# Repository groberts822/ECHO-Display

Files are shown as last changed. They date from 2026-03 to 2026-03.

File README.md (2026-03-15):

# ECHO-Display
ECHO, or Embedded Controller &amp; Hidden Operations. Music display by day, game console by night.
To begin, I started working on my schematic. It was quite simple, I chose to 2 1x7 headers instead of going through the pain to spend forever searching through the internet for the right symbol and footprint of the esp32. 
I prefer to use net labels, especially with schematics that are this simple, so here's my schematic below:



In addition, my PCB was quite simple, however it took some measurements, where I used the provided STEP files and just measured the necessary sizes in fusion. 
The 1x7 headers for the ESP32 ARE spaced out correctly (Again, made sure by measuring the part in fusion), and I made sure the display had enough space so it wouldnt cover the switches. I also chose to do the esp32 on the back side, the display ontop, and the switches lined up below the display. I also added mounting holes and added a custom logo to my pcb just for fun (and mounting holes for mounting to case). Below is the PCB: 



In addition, I used the provided STEP files to make the 3D viewer. Just a note, the DIsplay does not have headers in this 3D viewer, because they are specially spaced pins (3mm apart not 2.54mm), so I will have 
to use the header pins which come with the display itself. I also made sure to adjust the footprint so that it was actually 3mm apart and would work. Below is the 3D model: 



Backside: 



Next I saved the STEP for the board with the parts, and moved on over to fusion. I utilized the mounting holes and provided holes on each side of it, so I can use heat-set inserts on the bottom half, and then use screws to secure the top half and pcb into place. I chose to go with somewhat of a unique spotify display design, as I made it so the display was sideways and ontop, then the 3 switches below it, and it was like a stand proped up almost in the shape of an iphone holder. Below are some images of the 3D model: 









I would like to note, there are holes for heat-press inserts, which I have myself, alongside the proper screws, so unless it comes in the kit for this starter project, I dont need them hence why they aren't separately mentioned in the BOM. 

After basically finishing the whole 3D modelling and such, I worked on the firmware, where although I cannot put here, I provided a snippet of the code below, with the full thing being in the github repo:



BOM is below:

| Qty | Part | Link | Notes |
|-----|---|---|---|
| 1 | ESP32 LOLIN C3 Mini | [AliExpress](https://www.aliexpress.us/item/3256804553736450.html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) | |
| 1 | 1.8" TFT Display ST7735 | [AliExpress](https://www.aliexpress.us/item/3256809750593574.html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"order"%3A"199"%2C"eval"%3A"1"%2C"fromPage"%3A"search"%7D&pdp_npi=6%40dis%21USD%218.14%210.99%21%21%2155.72%216.76%21%40210311cc17736153139033443ee5db%2112000050625051194%21sea%21US%217425461850%21ABX%211%210%21n_tag%3A-29910%3Bd%3A6670291b%3Bm03_new_user%3A-29895%3BpisId%3A5000000197847475&curPageLogUid=sl2faarfQKwY&utparam-url=scene%3Asearch%7Cquery_from%3A%7Cx_object_id%3A1005009936908326%7C_p_origin_prod%3A&_gl=1*4nhmo6*_gcl_au*OTExMzQxMzAyLjE3NzM2MTUyNjg.*_ga*MTY2NjQwMzk4OC4xNzczNjE1MjY4*_ga_VED1YSGNC7*czE3NzM2MTUyNjgkbzEkZzEkdDE3NzM2MTUzMTIkajE2JGwwJGgw) | |
| 1 | Custom PCB | [JLCPCB](https://jlcpcb.com) | Already ordered |
| 3 | Cherry MX Switches | [NovelKeys](https://novelkeys.com/products/cherry-mx2a-switches) | Leftover from Hackpad |
| 3 | Keycaps (1u) | [NovelKeys](https://novelkeys.com) | Leftover from Hackpad |
| 4 | M3 Heatset Inserts | [Amazon](https://www.amazon.com/initeq-M3-0-5-Threaded-Inserts-Printing/dp/B077CJV3Z9) | Leftover from Hackpad |
| 4 | M3 Screws | [Amazon](https://www.amazon.com/s?k=m3+screws) | Leftover from Hackpad |

All files have been uploaded to the github repo, and just to be sure I had also provided the gerber files so its easier to just take them straight off of there when I order the pcb. 
Lastly, ECHO, or Embedded Controller & Hidden Operations (yes I know the name is weird, it'll make sense), is a desk Spotify display built using an ESP32 C3 Mini, alongside a 1.8" TFT screen, 3 mechanical switches for playback control, and a hidden Space Invaders game unlocked by holding all 3 keys (hence the "& Hidden Operations").
The display shows your current track with mood-based colors, scrolling text, animated bars, and a progress bar. The PCB was (although as expected) built in KiCad while the case was designed around the full PCB in Fusion360. 
The project includes a Case folder with CAD files, a PCB folder with all KiCad and manufacturing files, and Firmware folder with the Arduino firmware. 
I would also like to point out. The PCB was not needed for this project, however, I am still working on my PCB designing skills so I could use the challenge. Also, the firmware provided is NOT the final version, as I can only really finish it once I have the ESP32 and know its IP. 

Thanks for checking out ECHO. And don't forget to hold all 3 keys. 

Adobe Express - file

Github Repo Link: 
https://github.com/groberts822/ECHO-Display

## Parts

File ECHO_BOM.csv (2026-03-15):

Qty | Part | Link | Notes
----- | ------ | ------ | -------
1 | ESP32 LOLIN C3 Mini | [AliExpress](https://www.aliexpress.us/item/3256804553736450.html
1 | 1.8" TFT Display ST7735 | [AliExpress](https://www.aliexpress.us/item/3256809750593574.html?pdp_ext_f=%7B"order"%3A"199"%2C"eval"%3A"1"%2C"fromPage"%3A"search"%7D&pdp_npi=6%40dis%21USD%218.14%210.99%21%21%2155.72%216.76%21%40210311cc17736153139033443ee5db%2112000050625051194%21sea%21US%217425461850%21ABX%211%210%21n_tag%3A-29910%3Bd%3A6670291b%3Bm03_new_user%3A-29895%3BpisId%3A5000000197847475&curPageLogUid=sl2faarfQKwY&utparam-url=scene%3Asearch%7Cquery_from%3A%7Cx_object_id%3A1005009936908326%7C_p_origin_prod%3A&_gl=1*4nhmo6*_gcl_au*OTExMzQxMzAyLjE3NzM2MTUyNjg.*_ga*MTY2NjQwMzk4OC4xNzczNjE1MjY4*_ga_VED1YSGNC7*czE3NzM2MTUyNjgkbzEkZzEkdDE3NzM2MTUzMTIkajE2JGwwJGgw)
1 | Custom PCB | [JLCPCB](https://jlcpcb.com) | Already ordered to save time, dont need reimbursement or grant for this
3 | Cherry MX Switches | [NovelKeys](https://novelkeys.com/products/cherry-mx2a-switches) | Leftover from Hackpad, dont need grant for this
3 | Keycaps (1u) | [NovelKeys](https://novelkeys.com) | Leftover from Hackpad, dont need grant for this
4 | M3 Heatset Inserts | [Amazon](https://www.amazon.com/initeq-M3-0-5-Threaded-Inserts-Printing/dp/B077CJV3Z9) | Leftover from Hackpad, dont need grant for this
4 | M3 Screws | [Amazon](https://www.amazon.com/s?k=m3+screws) | Leftover from Hackpad, dont need grant for this

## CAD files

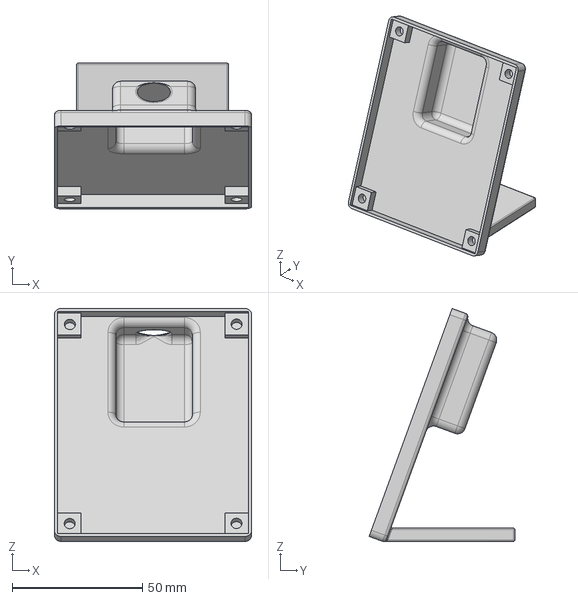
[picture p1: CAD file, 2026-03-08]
ECHO_CAD/ECHO Case (Bottom).step
75.7 x 55.9 x 89.4 mm

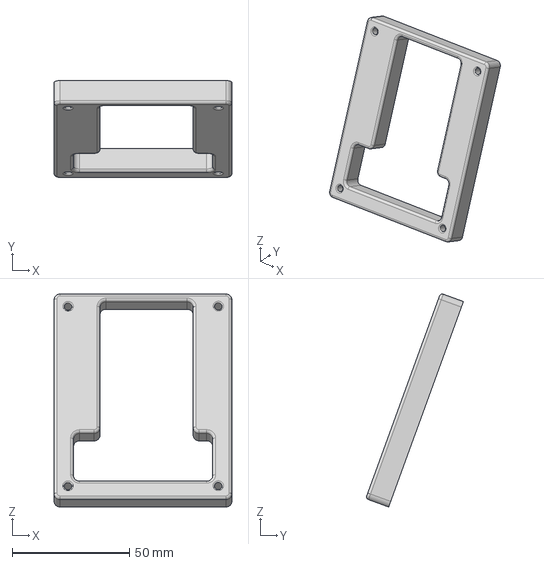
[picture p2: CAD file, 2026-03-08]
ECHO_CAD/ECHO Case (Top).step
75.7 x 41.3 x 90.7 mm

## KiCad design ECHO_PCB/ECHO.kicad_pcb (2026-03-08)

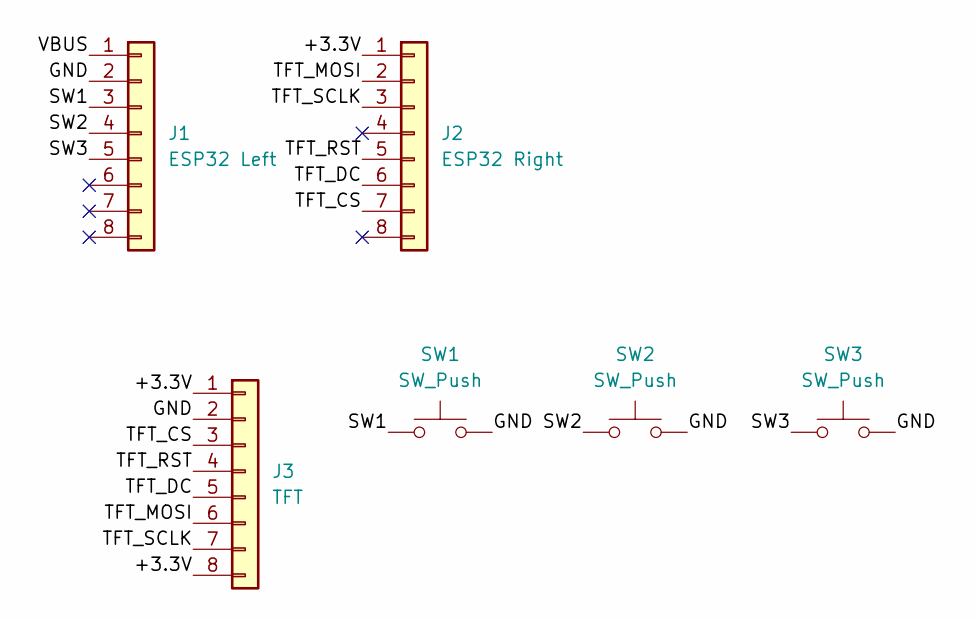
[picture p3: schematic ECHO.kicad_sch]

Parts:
J1: ESP32 Left; PinSocket_1x08_P2.54mm_Vertical
J2: ESP32 Right; PinSocket_1x08_P2.54mm_Vertical
J3: TFT; PinSocket_1x08_P2.54mm_Vertical
SW1, SW2, SW3: SW_Push; SW_Cherry_MX_1.00u_PCB

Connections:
/+3.3V: J2.1, J3.1, J3.8
/GND: J1.2, J3.2, SW1.2, SW2.2, SW3.2
/SW1: J1.3, SW1.1
/SW2: J1.4, SW2.1
/SW3: J1.5, SW3.1
/TFT_CS: J2.7, J3.3
/TFT_DC: J2.6, J3.5
/TFT_MOSI: J2.2, J3.6
/TFT_RST: J2.5, J3.4
/TFT_SCLK: J2.3, J3.7
/VBUS: J1.1

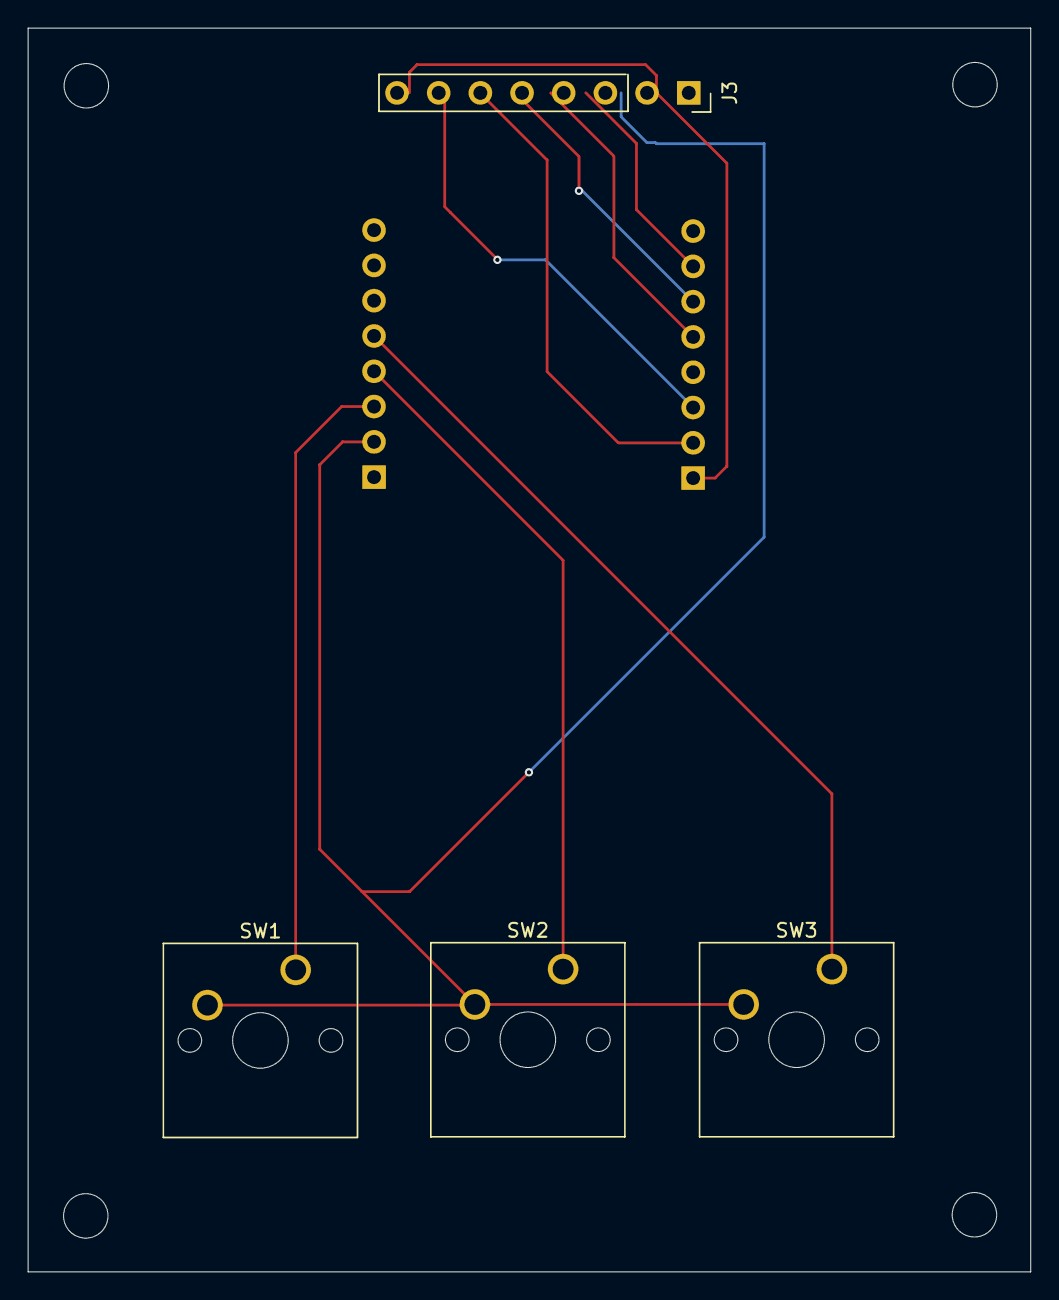
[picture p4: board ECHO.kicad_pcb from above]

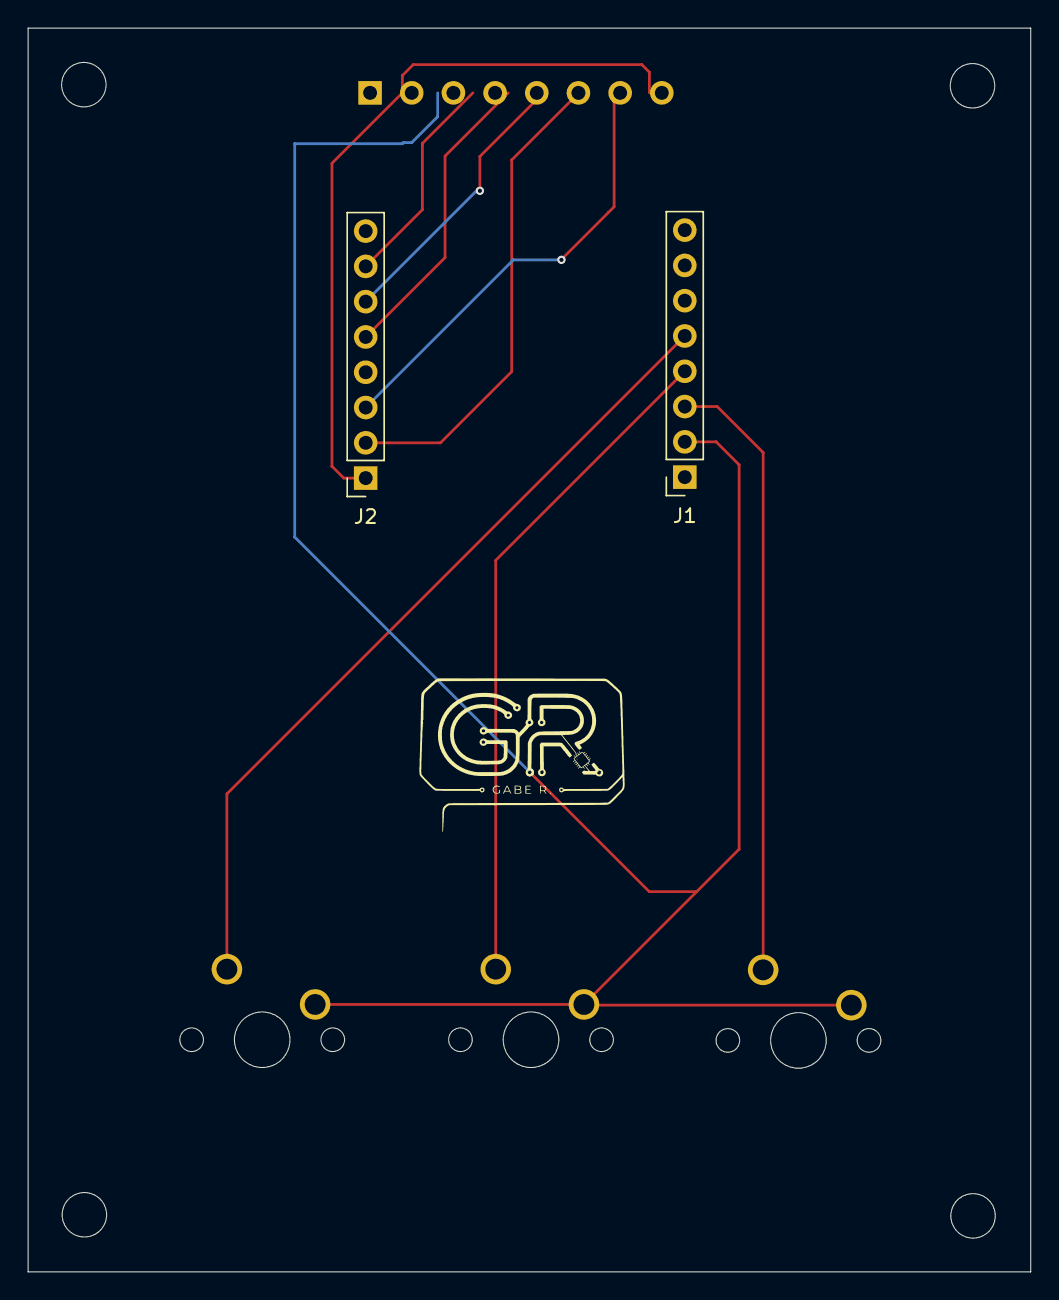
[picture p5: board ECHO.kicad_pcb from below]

Board: 2 copper layers, 72.2 x 89.5 mm, 6 parts (2 on the bottom side), 10 nets.

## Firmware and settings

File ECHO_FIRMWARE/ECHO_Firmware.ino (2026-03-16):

#include <Arduino.h>
#include <ArduinoJson.h>
#include <Adafruit_GFX.h>
#include <Adafruit_ST7735.h>
#include <WiFi.h>
#include <SpotifyEsp32.h>
#include <SPI.h>

char* SSID     = "My WiFi SSID";
char* PASS     = "My WiFi Password";
const char* CLID  = "My Spotify Client ID";
const char* CLSEC = "My Spotify Client Secret";

#define TFT_CS    3
#define TFT_RST   1
#define TFT_DC    2
#define TFT_SCLK  4
#define TFT_MOSI  5

#define BTN_L  6
#define BTN_M  7
#define BTN_R  8

Adafruit_ST7735 tft = Adafruit_ST7735(TFT_CS, TFT_DC, TFT_MOSI, TFT_SCLK, TFT_RST);
Spotify sp(CLID, CLSEC);

#define SW 160
#define SH 128

// rough mood colors - not using audio features api, just proxying off name length for now
// TODO: hook into actual valence/energy endpoint when i have time
#define C_HYPE   tft.color565(180, 0, 0)
#define C_HAPPY  tft.color565(180, 120, 0)
#define C_CHILL  tft.color565(0, 80, 160)
#define C_SAD    tft.color565(40, 0, 80)
#define C_DEF    tft.color565(0, 0, 0)

String trkName  = "";
String trkArtist = "";
bool   playing  = false;
int    scrollOff = 0;
unsigned long tScroll = 0;
unsigned long tPoll   = 0;
uint16_t moodCol = C_DEF;

int bH[3] = {10, 20, 15};
int bT[3] = {10, 20, 15};
unsigned long tBar = 0;

// progress is faked rn - SpotifyEsp32 doesnt expose it cleanly
// leaving at 0.5 until i find a workaround
float prog = 0.5;

bool b1Lst = HIGH, b2Lst = HIGH, b3Lst = HIGH;
unsigned long bHoldT = 0;
bool held = false;

bool gMode = false;

#define N_INV  12
#define N_BLTS  4

struct Inv { int x, y; bool alive; };
struct Blt { int x, y; bool on; };

Inv invs[N_INV];
Blt pBullets[N_BLTS];
Blt iBullet;

int pX    = SW / 2;
int lives = 3;
int score = 0;
int iDir  = 1;
unsigned long tTick = 0;
bool gOver = false;
bool gWon  = false;

void drawSp();
void drawBars();
uint16_t moodColor(String t);
void checkHold();
void runGame();
void initGame();
void drawGame();
void moveInvs();
void movePBullets();
void moveIBullet();
void checkHits();
void drawShip();
void clearShip(int x);
void scrGameOver();
void scrWin();

void setup() {
  Serial.begin(115200);

  pinMode(BTN_L, INPUT_PULLUP);
  pinMode(BTN_M, INPUT_PULLUP);
  pinMode(BTN_R, INPUT_PULLUP);

  tft.initR(INITR_BLACKTAB);
  tft.setRotation(1);
  tft.fillScreen(ST77XX_BLACK);

  tft.setTextSize(3);
  tft.setTextColor(ST77XX_WHITE);
  tft.setCursor(40, 50);
  tft.print("ECHO");
  delay(1000);
  tft.fillScreen(ST77XX_BLACK);

  tft.setTextSize(1);
  tft.setTextColor(ST77XX_WHITE);
  tft.setCursor(0, 0);
  tft.print("Connecting...");
  WiFi.begin(SSID, PASS);
  int dots = 0;
  while (WiFi.status() != WL_CONNECTED) {
    delay(500);
    tft.print(".");
    if (++dots > 20) {
      tft.fillScreen(ST77XX_BLACK);
      tft.setCursor(0, 0);
      dots = 0;
    }
  }

  tft.fillScreen(ST77XX_BLACK);
  tft.setCursor(0, 0);
  tft.print("WiFi up");
  tft.setCursor(0, 12);
  tft.print(WiFi.localIP().toString().c_str());
  delay(2000);

  tft.fillScreen(ST77XX_BLACK);
  tft.setCursor(0, 0);
  tft.print("Spotify auth...");
  tft.setCursor(0, 12);
  tft.print("open IP in browser");
  sp.begin();
  while (!sp.is_auth()) sp.handle_client();

  tft.fillScreen(ST77XX_BLACK);
  tft.setCursor(0, 0);
  tft.print("good to go");
  delay(800);
  tft.fillScreen(ST77XX_BLACK);
}

void loop() {
  checkHold();

  if (gMode) {
    runGame();
    return;
  }

  if (millis() - tPoll > 2000) {
    tPoll = millis();
    drawSp();
  }

  // scroll if name too long
  if (millis() - tScroll > 200 && trkName.length() > 18) {
    tScroll = millis();
    if (++scrollOff > (int)trkName.length()) scrollOff = 0;
    tft.fillRect(0, 40, SW, 16, moodCol);
    tft.setTextColor(ST77XX_WHITE);
    tft.setTextSize(2);
    tft.setCursor(0, 40);
    String s = trkName.substring(scrollOff) + "   " + trkName.substring(0, scrollOff);
    tft.print(s.substring(0, 13));
  }

  if (millis() - tBar > 150 && playing) {
    tBar = millis();
    drawBars();
  }
}

void drawSp() {
  String trk = sp.current_track_name();
  String art  = sp.current_artist_names();
  bool   isP  = sp.is_playing();

  if (trk == "Something went wrong" || trk == "null" || trk.isEmpty()) return;

  bool changed = (trk != trkName || art != trkArtist || isP != playing);
  if (!changed) {
    // still update progress bar even if nothing changed
    int bw = (int)(prog * SW);
    tft.fillRect(0, SH - 6, SW, 6, tft.color565(50, 50, 50));
    tft.fillRect(0, SH - 6, bw, 6, ST77XX_GREEN);
    return;
  }

  trkName   = trk;
  trkArtist = art;
  playing   = isP;
  scrollOff = 0;

  moodCol = moodColor(trk);
  tft.fillScreen(moodCol);

  tft.setTextSize(1);
  tft.setTextColor(ST77XX_WHITE);
  tft.setCursor(0, 0);
  tft.print(isP ? ">> NOW PLAYING" : "|| PAUSED");

  tft.setCursor(0, 20);
  String a = art.length() > 26 ? art.substring(0, 26) : art;
  tft.print(a.c_str());

  tft.setTextSize(2);
  tft.setCursor(0, 40);
  tft.print(trk.substring(0, 13).c_str());

  drawBars();

  int bw = (int)(prog * SW);
  tft.fillRect(0, SH - 6, SW, 6, tft.color565(50, 50, 50));
  tft.fillRect(0, SH - 6, bw, 6, ST77XX_GREEN);
}

void drawBars() {
  int bw = 8, gap = 4;
  int sx = SW - (3 * bw + 2 * gap) - 4;
  int by = SH - 10;
  int mh = 30;

  for (int i = 0; i < 3; i++) {
    if (random(10) > 6) bT[i] = random(6, mh);
    if (bH[i] < bT[i]) bH[i]++;
    else if (bH[i] > bT[i]) bH[i]--;
    int x = sx + i * (bw + gap);
    tft.fillRect(x, by - mh, bw, mh, moodCol);
    tft.fillRect(x, by - bH[i], bw, bH[i], ST77XX_GREEN);
  }
}

uint16_t moodColor(String t) {
  int l = t.length();
  if (l < 5)  return C_SAD;
  if (l < 10) return C_CHILL;
  if (l < 15) return C_HAPPY;
  return C_HYPE;
}

void checkHold() {
  bool b1 = digitalRead(BTN_L) == LOW;
  bool b2 = digitalRead(BTN_M) == LOW;
  bool b3 = digitalRead(BTN_R) == LOW;

  if (b1 && b2 && b3) {
    if (!held) { held = true; bHoldT = millis(); }
    else if (millis() - bHoldT > 2000) {
      gMode = !gMode;
      held  = false;
      if (gMode) initGame();
      else { tft.fillScreen(ST77XX_BLACK); trkName = ""; }
      delay(500);
    }
  } else {
    held = false;
  }
}

void initGame() {
  tft.fillScreen(ST77XX_BLACK);
  pX = SW / 2; lives = 3; score = 0;
  gOver = false; gWon = false; iDir = 1;

  for (int i = 0; i < N_BLTS; i++) pBullets[i].on = false;
  iBullet.on = false;

  int idx = 0;
  for (int r = 0; r < 3; r++)
    for (int c = 0; c < 4; c++)
      invs[idx++] = { 10 + c * 35, 10 + r * 18, true };

  drawGame();
}

void runGame() {
  if (gOver) { scrGameOver(); return; }
  if (gWon)  { scrWin();      return; }

  bool b1 = digitalRead(BTN_L) == LOW;
  bool b2 = digitalRead(BTN_M) == LOW;
  bool b3 = digitalRead(BTN_R) == LOW;

  if (b1 && pX > 4)         { clearShip(pX); pX -= 3; }
  if (b3 && pX < SW - 12)   { clearShip(pX); pX += 3; }

  static unsigned long tShot = 0;
  if (b2 && millis() - tShot > 300) {
    tShot = millis();
    for (int i = 0; i < N_BLTS; i++) {
      if (!pBullets[i].on) {
        pBullets[i] = { pX + 4, SH - 20, true };
        break;
      }
    }
  }

  if (millis() - tTick > 60) {
    tTick = millis();
    moveInvs(); movePBullets(); moveIBullet(); checkHits(); drawGame();
  }
}

void drawGame() {
  tft.fillScreen(ST77XX_BLACK);
  tft.setTextSize(1);
  tft.setTextColor(ST77XX_WHITE);
  tft.setCursor(0, 0);  tft.print("SC:"); tft.print(score);
  tft.setCursor(100, 0); tft.print("HP:"); tft.print(lives);

  for (int i = 0; i < N_INV; i++) {
    if (!invs[i].alive) continue;
    tft.fillRect(invs[i].x, invs[i].y, 10, 8, ST77XX_GREEN);
    tft.drawPixel(invs[i].x + 2, invs[i].y - 2, ST77XX_GREEN);
    tft.drawPixel(invs[i].x + 7, invs[i].y - 2, ST77XX_GREEN);
  }

  for (int i = 0; i < N_BLTS; i++)
    if (pBullets[i].on)
      tft.fillRect(pBullets[i].x, pBullets[i].y, 2, 6, ST77XX_YELLOW);

  if (iBullet.on)
    tft.fillRect(iBullet.x, iBullet.y, 2, 6, ST77XX_RED);

  drawShip();
}

void drawShip() {
  tft.fillTriangle(pX, SH-10, pX+8, SH-10, pX+4, SH-18, ST77XX_CYAN);
}

void clearShip(int x) {
  tft.fillRect(x, SH - 20, 10, 12, ST77XX_BLACK);
}

void moveInvs() {
  static int mv = 0;
  if (++mv < 3) return;
  mv = 0;

  bool edge = false;
  for (int i = 0; i < N_INV; i++) {
    if (!invs[i].alive) continue;
    invs[i].x += iDir * 2;
    if (invs[i].x > SW - 12 || invs[i].x < 0) edge = true;
  }
  if (edge) {
    iDir *= -1;
    for (int i = 0; i < N_INV; i++)
      if (invs[i].alive) invs[i].y += 6;
  }

  if (!iBullet.on && random(20) == 0) {
    int s = random(N_INV);
    for (int i = 0; i < N_INV; i++) {
      int idx = (s + i) % N_INV;
      if (invs[idx].alive) {
        iBullet = { invs[idx].x + 4, invs[idx].y + 8, true };
        break;
      }
    }
  }
}

void movePBullets() {
  for (int i = 0; i < N_BLTS; i++) {
    if (!pBullets[i].on) continue;
    pBullets[i].y -= 5;
    if (pBullets[i].y < 0) pBullets[i].on = false;
  }
}

void moveIBullet() {
  if (!iBullet.on) return;
  iBullet.y += 4;
  if (iBullet.y > SH) iBullet.on = false;
}

void checkHits() {
  for (int b = 0; b < N_BLTS; b++) {
    if (!pBullets[b].on) continue;
    for (int i = 0; i < N_INV; i++) {
      if (!invs[i].alive) continue;
      if (pBullets[b].x >= invs[i].x && pBullets[b].x <= invs[i].x + 10 &&
          pBullets[b].y >= invs[i].y && pBullets[b].y <= invs[i].y + 8) {
        invs[i].alive  = false;
        pBullets[b].on = false;
        score += 10;
      }
    }
  }

  if (iBullet.on &&
      iBullet.x >= pX && iBullet.x <= pX + 8 &&
      iBullet.y >= SH - 18) {
    iBullet.on = false;
    if (--lives <= 0) gOver = true;
  }

  for (int i = 0; i < N_INV; i++)
    if (invs[i].alive && invs[i].y >= SH - 20) gOver = true;

  bool any = false;
  for (int i = 0; i < N_INV; i++) if (invs[i].alive) { any = true; break; }
  if (!any) gWon = true;
}

void scrGameOver() {
  tft.fillScreen(ST77XX_BLACK);
  tft.setTextColor(ST77XX_RED);
  tft.setTextSize(2);
  tft.setCursor(20, 40);
  tft.print("GAME OVER");
  tft.setTextColor(ST77XX_WHITE);
  tft.setTextSize(1);
  tft.setCursor(30, 70); tft.print("SCORE: "); tft.print(score);
  tft.setCursor(10, 90); tft.print("hold all 3 to exit");
  delay(200);
}

void scrWin() {
  tft.fillScreen(ST77XX_BLACK);
  tft.setTextColor(ST77XX_GREEN);
  tft.setTextSize(2);
  tft.setCursor(30, 40);
  tft.print("YOU WIN!");
  tft.setTextColor(ST77XX_WHITE);
  tft.setTextSize(1);
  tft.setCursor(30, 70); tft.print("SCORE: "); tft.print(score);
  tft.setCursor(10, 90); tft.print("hold all 3 to exit");
  delay(200);
}
